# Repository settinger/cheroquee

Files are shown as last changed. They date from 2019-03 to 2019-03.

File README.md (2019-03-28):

# Cheroquee

A proof-of-concept scrolling LED marquee with support for Cherokee input. Could easily be extended to support variable-width glyphs, fancier scrolling, pre-programmed text cycles, etc. Potentially useful as a starting point for other orthographies that don't have pixel fonts: Inuktitut, N'Ko, maybe vertical Mongolian?

Requires [py-spidev](https://pypi.org/project/spidev/). `pip install py-spidev`

Usage: `python3 cheroquee.py MESSAGE`, e.g. `python3 cheroquee.py "ᏣᎳᎩᎯ ᎠᏰᎵ"`

For more info: www.settinger.net/projects.php?project=cheroquee

* * * * *

## Cultural note

Let's be clear, I'm a white non-Cherokee-speaker showing off a potential tech tool for Cherokee-speakers. I worry about being insensitive, insulting, condescending, or inaccurate; I strive to be none of those things as I present this project. But if I screw up or speak out-of-turn, please tell me!

My scope and intentions are pretty small, here. There's a long history of prescriptivist anglophones unceremoniously thrusting new language tools on people, and I am not trying to be that! There are lots of immediately-apparent ways to improve it, however, **I'll only continue this project if someone else has a real, acceptable use for it**. If you write to me with one, I'll work with you at whatever level of involvement you deem appropriate. Thanks.

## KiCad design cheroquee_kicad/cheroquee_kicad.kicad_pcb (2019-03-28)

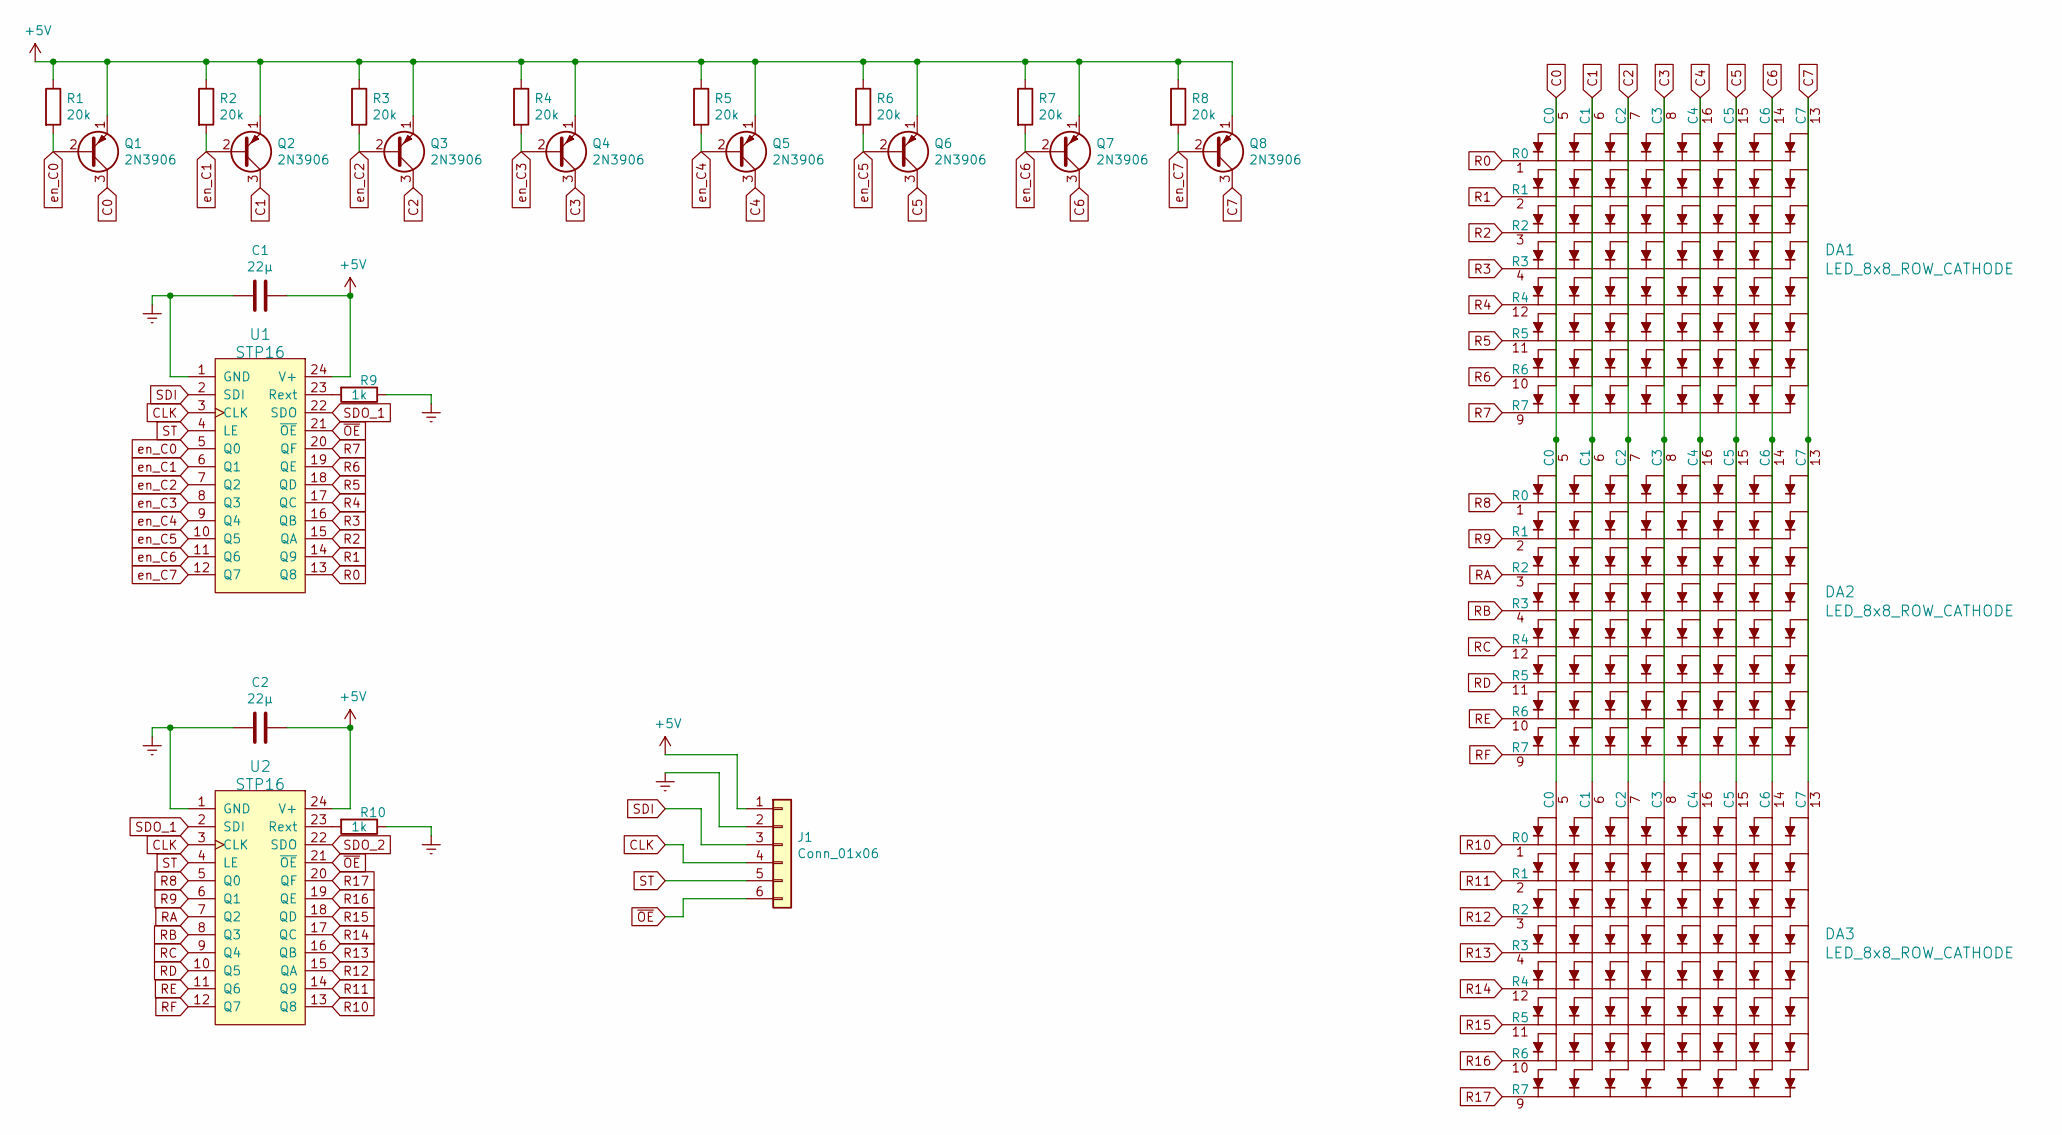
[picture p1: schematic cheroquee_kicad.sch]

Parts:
C1, C2: 22μ; Pin_Header_Straight_1x02_Pitch2.54mm
DA1, DA2, DA3: LED_8x8_ROW_CATHODE; 8x8_LED
J1: Conn_01x06; Socket_Strip_Straight_1x06_Pitch2.54mm
Q1, Q2, Q3, Q4, Q5, Q6, Q7, Q8: 2N3906; breadboard_transistor
R1, R2, R3, R4, R5, R6, R7, R8: 20k; Pin_Header_Straight_1x02_Pitch2.54mm
R9, R10: 1k; Pin_Header_Straight_1x02_Pitch2.54mm
U1, U2: STP16; stp16_breakout_alt

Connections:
+5V: C1.1, C2.1, J1.1, Q1.1 (E), Q2.1 (E), Q3.1 (E), Q4.1 (E), Q5.1 (E), Q6.1 (E), Q7.1 (E), Q8.1 (E), R1.1, R2.1, R3.1, R4.1, R5.1, R6.1, R7.1, R8.1, U1.24 (V+), U2.24 (V+)
C0: DA1.5 (C0), DA2.5 (C0), DA3.5 (C0), Q1.3 (C)
C1: DA1.6 (C1), DA2.6 (C1), DA3.6 (C1), Q2.3 (C)
C2: DA1.7 (C2), DA2.7 (C2), DA3.7 (C2), Q3.3 (C)
C3: DA1.8 (C3), DA2.8 (C3), DA3.8 (C3), Q4.3 (C)
C4: DA1.16 (C4), DA2.16 (C4), DA3.16 (C4), Q5.3 (C)
C5: DA1.15 (C5), DA2.15 (C5), DA3.15 (C5), Q6.3 (C)
C6: DA1.14 (C6), DA2.14 (C6), DA3.14 (C6), Q7.3 (C)
C7: DA1.13 (C7), DA2.13 (C7), DA3.13 (C7), Q8.3 (C)
CLK: J1.4, U1.3 (CLK), U2.3 (CLK)
GNDREF: C1.2, C2.2, J1.2, R9.1, R10.1, U1.1 (GND), U2.1 (GND)
unnamed: R9.2, U1.23 (Rext)
unnamed: R10.2, U2.23 (Rext)
R0: DA1.1 (R0), U1.13 (Q8)
R1: DA1.2 (R1), U1.14 (Q9)
R2: DA1.3 (R2), U1.15 (QA)
R3: DA1.4 (R3), U1.16 (QB)
R4: DA1.12 (R4), U1.17 (QC)
R5: DA1.11 (R5), U1.18 (QD)
R6: DA1.10 (R6), U1.19 (QE)
R7: DA1.9 (R7), U1.20 (QF)
R8: DA2.1 (R0), U2.5 (Q0)
R9: DA2.2 (R1), U2.6 (Q1)
R10: DA3.1 (R0), U2.13 (Q8)
R11: DA3.2 (R1), U2.14 (Q9)
R12: DA3.3 (R2), U2.15 (QA)
R13: DA3.4 (R3), U2.16 (QB)
R14: DA3.12 (R4), U2.17 (QC)
R15: DA3.11 (R5), U2.18 (QD)
R16: DA3.10 (R6), U2.19 (QE)
R17: DA3.9 (R7), U2.20 (QF)
RA: DA2.3 (R2), U2.7 (Q2)
RB: DA2.4 (R3), U2.8 (Q3)
RC: DA2.12 (R4), U2.9 (Q4)
RD: DA2.11 (R5), U2.10 (Q5)
RE: DA2.10 (R6), U2.11 (Q6)
RF: DA2.9 (R7), U2.12 (Q7)
SDI: J1.3, U1.2 (SDI)
SDO_1: U1.22 (SDO), U2.2 (SDI)
SDO_2: U2.22 (SDO)
ST: J1.5, U1.4 (LE), U2.4 (LE)
en_C0: Q1.2 (B), R1.2, U1.5 (Q0)
en_C1: Q2.2 (B), R2.2, U1.6 (Q1)
en_C2: Q3.2 (B), R3.2, U1.7 (Q2)
en_C3: Q4.2 (B), R4.2, U1.8 (Q3)
en_C4: Q5.2 (B), R5.2, U1.9 (Q4)
en_C5: Q6.2 (B), R6.2, U1.10 (Q5)
en_C6: Q7.2 (B), R7.2, U1.11 (Q6)
en_C7: Q8.2 (B), R8.2, U1.12 (Q7)
~OE: J1.6, U1.21 (~OE), U2.21 (~OE)

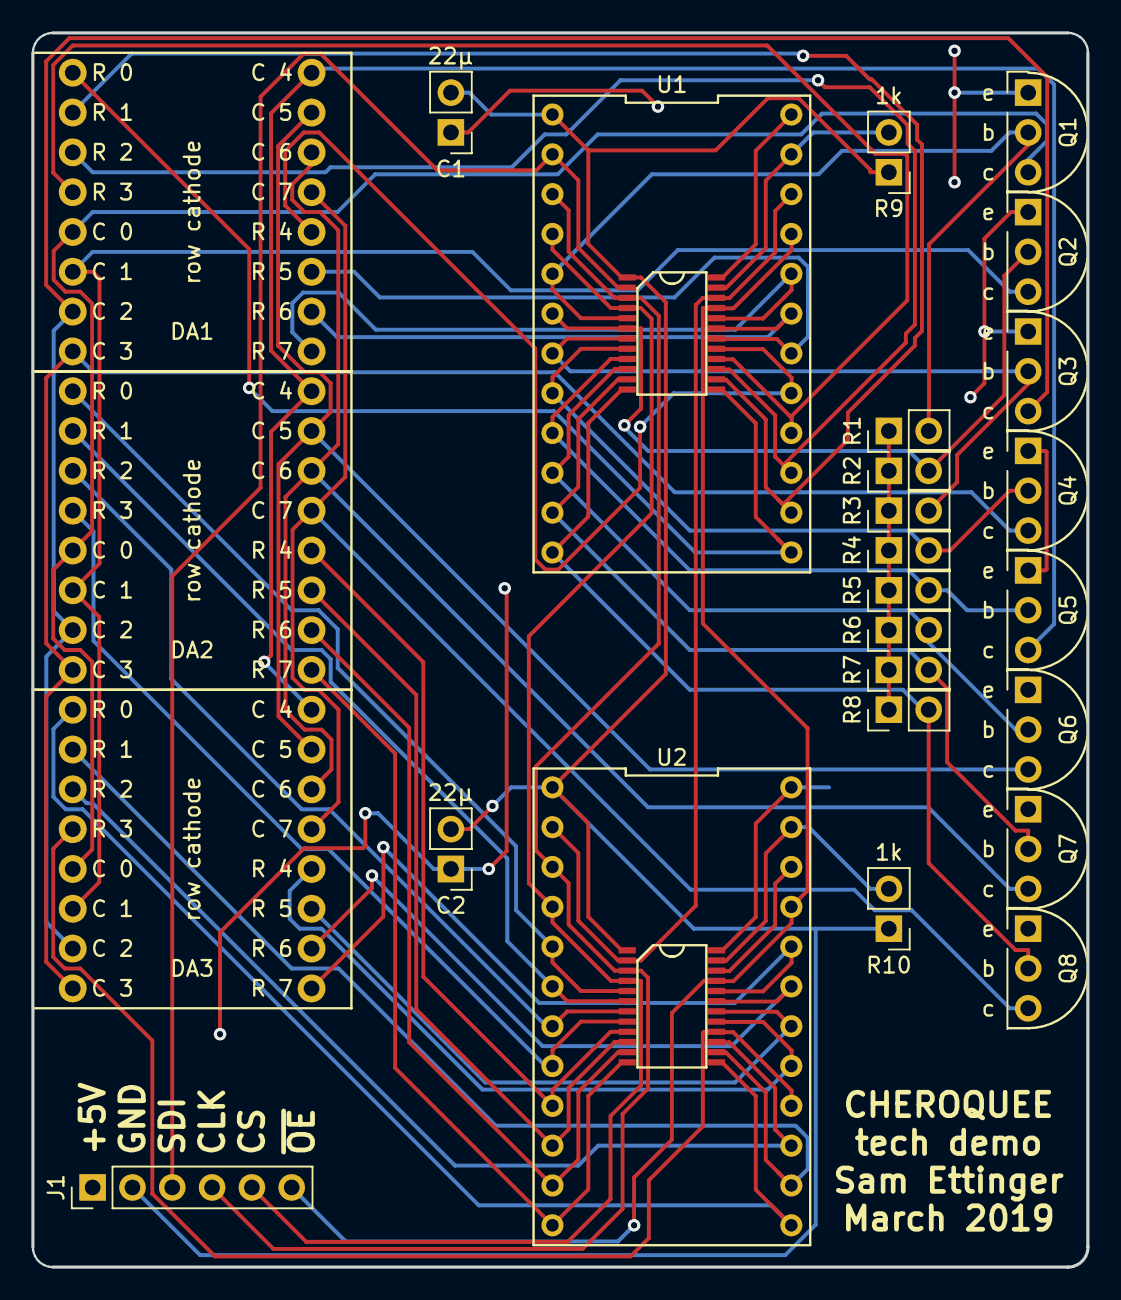
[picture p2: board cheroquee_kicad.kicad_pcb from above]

Board: 2 copper layers, 67.3 x 78.7 mm, 26 parts (0 on the bottom side), 49 nets.

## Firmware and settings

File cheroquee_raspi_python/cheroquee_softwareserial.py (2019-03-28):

# -*- coding: utf-8 -*-
"""
Use standard shift-register LED-driver communication protocol to drive an 8-pixel high scrolling marquee

@author: Sam
"""

from chardict import chardict
from bytemanip import byteToArray
import stp16
import sys
import numpy as np
import time

## definitions:
# Number of 8x8 panels
SIZE = 1

# Frames per second
FPS = 8

# Column refresh rate
f_refresh = 288

# (Ideally) frequency of PWM for LEDs
f_PWM = 500


## Check if a message was passed when the command line argument was called
arguments = len(sys.argv)-1

# If a message was passed, display it on the marquee; else, display default 
if arguments == 1:
    message = str(sys.argv[1])
else:
    message = u"ᏣᎳᎩᎯ ᎠᏰᎵ"

# Convert message to pixel array
# fullArray = np.zeros((8,8*(len(message)+3)))  # The "+3 is to add some padding between loops
fullArray = np.zeros((8,8*(len(message))))  # The "+3 is to add some padding between loops
for index, glyph in enumerate(message):
    columnstart = index*8
    glyphbytes = chardict[glyph]
    for row in range(8):
        fullArray[row, columnstart:columnstart+8] = byteToArray(glyphbytes[row])

# Initialize the marquee array
marqueeArray = np.zeros((8, 8*(SIZE+1)))
# Add the column-control signal to the end of the array
for x in range(8):
    marqueeArray[x,(8*SIZE)+x] = 1

# Initialize the marquee communications
stp16.init()

## Do a loop
columnPeriod = 1./f_refresh
framePeriod = 1./FPS

newColumn = 0
currTime = time.time()

while(1):
    # Transmit the marquee until it's time to update again
    frameStartTime = time.time()
    while (currTime-frameStartTime < framePeriod):
        # Transmit all eight rows
        for row in range(8):
            colStartTime = time.time()
            stp16.transmitBool(marqueeArray[row,:])
            while (currTime-colStartTime < columnPeriod):
                currTime = time.time()
        currTime = time.time()

    # update marquee
    marqueeArray[:, 0:-9] = marqueeArray[:, 1:-8]
    marqueeArray[:,-9] = fullArray[:,newColumn]
    newColumn += 1
    newColumn = newColumn % len(fullArray[0,:])

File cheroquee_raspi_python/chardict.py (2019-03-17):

# -*- coding: utf-8 -*-
# todo: make a version that isn't fixed-width


A   = [0x00, 0xf0, 0x88, 0x84, 0x84, 0x84, 0x88, 0xf0]
Ga  = [0x00, 0x38, 0x44, 0x20, 0x7c, 0x08, 0x44, 0x38]
Ka  = [0x00, 0x18, 0x04, 0x62, 0xa2, 0xa2, 0x44, 0x38]
Ha  = [0x00, 0x38, 0x10, 0x50, 0xbe, 0x52, 0x14, 0x18]
La  = [0x00, 0x82, 0x82, 0x92, 0x54, 0x54, 0x54, 0x28]
Ma  = [0x00, 0x1c, 0x08, 0x18, 0xe6, 0x50, 0x50, 0x20]
Na  = [0x00, 0x30, 0x48, 0x84, 0xfc, 0x84, 0x48, 0x30]
Hna = [0x00, 0x40, 0xe0, 0x40, 0x5c, 0x48, 0x38, 0x08]
Nah = [0x00, 0x38, 0x44, 0x80, 0x9c, 0x84, 0x44, 0x3c]
Qua = [0x00, 0xfe, 0x10, 0x10, 0x10, 0x10, 0x10, 0xfe]
S   = [0x00, 0x38, 0x44, 0x02, 0x1a, 0x52, 0xb2, 0x5c]
Sa  = [0x00, 0x84, 0x84, 0x84, 0xfc, 0x84, 0x48, 0x30]
Da  = [0x00, 0x40, 0x40, 0x40, 0x40, 0x44, 0x44, 0x38]
Ta  = [0x00, 0xaa, 0xaa, 0x92, 0x54, 0x54, 0x54, 0x28]
Dla = [0x00, 0x10, 0x28, 0x10, 0x6c, 0xaa, 0xaa, 0x44]
Tla = [0x00, 0x18, 0x24, 0x44, 0x40, 0x40, 0x40, 0x7c]
Tsa = [0x00, 0x38, 0x44, 0x8e, 0x80, 0x80, 0x44, 0x38]
Wa  = [0x00, 0x38, 0x44, 0x80, 0x80, 0x9c, 0x48, 0x36]
Ya  = [0x00, 0x1c, 0x22, 0x02, 0xba, 0x92, 0x92, 0x6c]

E   = [0x00, 0xf0, 0x88, 0x88, 0xf0, 0x90, 0x94, 0x8c]
Ge  = [0x00, 0x70, 0x20, 0x24, 0x34, 0x28, 0x20, 0x70]
He  = [0x00, 0x78, 0x84, 0x04, 0x24, 0x38, 0x20, 0x70]
Le  = [0x00, 0x0c, 0x10, 0x10, 0x70, 0x88, 0x88, 0x70]
Me  = [0x00, 0x22, 0x52, 0x8a, 0x8e, 0x8a, 0x52, 0x22]
Ne  = [0x00, 0x18, 0x24, 0x24, 0x24, 0x44, 0x44, 0xc4]
Que = [0x00, 0x1c, 0x22, 0x02, 0x82, 0x92, 0x92, 0x6c]
Se  = [0x00, 0x18, 0x28, 0x48, 0x88, 0xfc, 0x08, 0x08]
De  = [0x00, 0x70, 0x8c, 0x40, 0x3c, 0x10, 0x88, 0x70]
Te  = [0x00, 0xe0, 0x20, 0x28, 0x24, 0x24, 0x24, 0x18]
Tle = [0x00, 0x40, 0x40, 0x40, 0x40, 0x40, 0x40, 0x7c]
Tse = [0x00, 0xe4, 0x24, 0x28, 0x28, 0x30, 0x30, 0x20]
We  = [0x00, 0x26, 0x55, 0x55, 0x53, 0x51, 0x22, 0xdc] # Consider shifting everything one bit to the left
Ye  = [0x00, 0x38, 0x44, 0x58, 0x44, 0x44, 0xf8, 0x40]

I   = [0x00, 0xfe, 0x10, 0x10, 0x10, 0x10, 0x10, 0x10]
Gi  = [0x00, 0x44, 0x44, 0x24, 0x18, 0x08, 0x10, 0xe0]
Hi  = [0x00, 0x18, 0x24, 0x24, 0x3c, 0x44, 0x44, 0x88]
Li  = [0x00, 0x18, 0x24, 0x44, 0x40, 0x40, 0x40, 0x40]
Mi  = [0x00, 0x84, 0x84, 0x84, 0xfc, 0x84, 0x84, 0x84]
Ni  = [0x00, 0x40, 0x40, 0x40, 0x78, 0x44, 0x44, 0x44]
Qui = [0x00, 0xdc, 0x22, 0x52, 0x54, 0x50, 0x50, 0x20]
Si  = [0x00, 0x40, 0x40, 0x78, 0x44, 0x44, 0x44, 0x78]
Di  = [0x00, 0x04, 0x04, 0x04, 0x04, 0x0c, 0x94, 0x64]
Ti  = [0x00, 0x3c, 0x04, 0x04, 0x04, 0x0c, 0x94, 0x64]
Tli = [0x00, 0x3c, 0x44, 0x80, 0x80, 0x80, 0x44, 0x38]
Tsi = [0x00, 0x80, 0x80, 0xbc, 0xca, 0x88, 0x88, 0x88]
Wi  = [0x00, 0x38, 0x44, 0xe2, 0x92, 0x8e, 0x44, 0x38]
Yi  = [0x00, 0x1c, 0x08, 0x1c, 0x22, 0xa6, 0xaa, 0x44]

O   = [0x00, 0x1c, 0x08, 0x1c, 0x62, 0xa2, 0xaa, 0x44]
Go  = [0x00, 0x10, 0x28, 0x28, 0x44, 0x7c, 0x82, 0x82]
Ho  = [0x00, 0x70, 0x20, 0x20, 0x3c, 0x20, 0x20, 0x70]
Lo  = [0x00, 0x38, 0x44, 0x90, 0x98, 0x94, 0x44, 0x38]
Mo  = [0x00, 0x38, 0x10, 0x38, 0x04, 0x04, 0x44, 0x38]
No  = [0x00, 0xfc, 0x08, 0x10, 0x20, 0x40, 0x80, 0xfc]
Quo = [0x00, 0xcc, 0x4f, 0x25, 0x28, 0x28, 0x10, 0x10]
So  = [0x00, 0x38, 0x10, 0x58, 0x34, 0x10, 0x10, 0x38]
Do  = [0x00, 0x84, 0x84, 0x84, 0x48, 0x48, 0x30, 0x30]
Tlo = [0x00, 0x04, 0x44, 0xa4, 0x7e, 0x24, 0x24, 0x18]
Tso = [0x00, 0x44, 0x48, 0x50, 0x60, 0x50, 0x48, 0x44]
Wo  = [0x00, 0x48, 0xa4, 0xa4, 0xa4, 0xc4, 0x88, 0x70]
Yo  = [0x00, 0x38, 0x44, 0x80, 0xb8, 0xc4, 0x84, 0x84]

U   = [0x00, 0x24, 0x52, 0x8a, 0x8c, 0x88, 0x50, 0x20]
Gu  = [0x00, 0x04, 0x04, 0x04, 0x04, 0x44, 0x44, 0x38]
Hu  = [0x00, 0x3c, 0x20, 0x20, 0x20, 0x20, 0x20, 0x20]
Lu  = [0x00, 0x82, 0xc6, 0xc6, 0xaa, 0xaa, 0x92, 0x92]
Mu  = [0x00, 0x27, 0x22, 0x12, 0x0c, 0xe4, 0x48, 0x30]
Nu  = [0x00, 0x78, 0xc4, 0x04, 0xc4, 0x7c, 0x04, 0x04]
Quu = [0x00, 0x00, 0x04, 0x02, 0x8a, 0x92, 0x92, 0x6c]
Su  = [0x00, 0x60, 0xac, 0x70, 0x40, 0x4c, 0x44, 0x38]
Du  = [0x00, 0x38, 0x44, 0x20, 0x10, 0x08, 0x44, 0x38]
Tlu = [0x00, 0x36, 0x48, 0xd4, 0x14, 0x14, 0x14, 0x08]
Tsu = [0x00, 0x04, 0x04, 0x34, 0x4c, 0x84, 0x48, 0x30]
Wu  = [0x00, 0x08, 0x14, 0x14, 0x14, 0x14, 0x88, 0x70]
Yu  = [0x00, 0x3a, 0x45, 0x80, 0x80, 0x8e, 0x44, 0x38]

V   = [0x00, 0x00, 0x10, 0x00, 0x10, 0x10, 0x10, 0x38]
Gv  = [0x00, 0xfc, 0x80, 0x80, 0xf8, 0x80, 0x80, 0xfc]
Hv  = [0x00, 0x20, 0x50, 0x50, 0x50, 0x56, 0x24, 0xd8]
Lv  = [0x00, 0x78, 0x04, 0x44, 0x64, 0x5c, 0x04, 0x04]
Mv  = [0x00, 0x30, 0x40, 0x80, 0x80, 0x9c, 0x88, 0x78] # Unused
Nv  = [0x00, 0x20, 0x50, 0x88, 0x8d, 0x8a, 0x50, 0x20]
Quv = [0x00, 0x70, 0x88, 0x80, 0x48, 0x84, 0x84, 0x78]
Sv  = [0x00, 0x78, 0x44, 0x44, 0x58, 0x48, 0x44, 0x44]
Dv  = [0x00, 0x76, 0xaa, 0xa0, 0xa0, 0xa0, 0xa0, 0x40]
Tlv = [0x00, 0x78, 0x44, 0x44, 0x78, 0x40, 0x40, 0x40]
Tsv = [0x00, 0x35, 0x4a, 0x80, 0x80, 0x80, 0x4a, 0x35]
Wv  = [0x00, 0x18, 0x20, 0x40, 0x78, 0x44, 0x44, 0x38]
Yv  = [0x00, 0x78, 0x44, 0x44, 0x78, 0x44, 0x44, 0x78]

Blank = [0x00, 0x00, 0x00, 0x00, 0x00, 0x00, 0x00, 0x00]

chardict = {\
u'Ꭰ': A,
u'Ꭱ': E,
u'Ꭲ': I,
u'Ꭳ': O,
u'Ꭴ': U,
u'Ꭵ': V,
u'Ꭶ': Ga,
u'Ꭷ': Ka,
u'Ꭸ': Ge,
u'Ꭹ': Gi,
u'Ꭺ': Go,
u'Ꭻ': Gu,
u'Ꭼ': Gv,
u'Ꭽ': Ha,
u'Ꭾ': He,
u'Ꭿ': Hi,
u'Ꮀ': Ho,
u'Ꮁ': Hu,
u'Ꮂ': Hv,
u'Ꮃ': La,
u'Ꮄ': Le,
u'Ꮅ': Li,
u'Ꮆ': Lo,
u'Ꮇ': Lu,
u'Ꮈ': Lv,
u'Ꮉ': Ma,
u'Ꮊ': Me,
u'Ꮋ': Mi,
u'Ꮌ': Mo,
u'Ꮍ': Mu,
u'Ᏽ': Mv,
u'Ꮎ': Na,
u'Ꮏ': Hna,
u'Ꮐ': Nah,
u'Ꮑ': Ne,
u'Ꮒ': Ni,
u'Ꮓ': No,
u'Ꮔ': Nu,
u'Ꮕ': Nv,
u'Ꮖ': Qua,
u'Ꮗ': Que,
u'Ꮘ': Qui,
u'Ꮙ': Quo,
u'Ꮚ': Quu,
u'Ꮛ': Quv,
u'Ꮜ': Sa,
u'Ꮝ': S,
u'Ꮞ': Se,
u'Ꮟ': Si,
u'Ꮠ': So,
u'Ꮡ': Su,
u'Ꮢ': Sv,
u'Ꮣ': Da,
u'Ꮤ': Ta,
u'Ꮥ': De,
u'Ꮦ': Te,
u'Ꮧ': Di,
u'Ꮨ': Ti,
u'Ꮩ': Do,
u'Ꮪ': Du,
u'Ꮫ': Dv,
u'Ꮬ': Dla,
u'Ꮭ': Tla,
u'Ꮮ': Tle,
u'Ꮯ': Tli,
u'Ꮰ': Tlo,
u'Ꮱ': Tlu,
u'Ꮲ': Tlv,
u'Ꮳ': Tsa,
u'Ꮴ': Tse,
u'Ꮵ': Tsi,
u'Ꮶ': Tso,
u'Ꮷ': Tsu,
u'Ꮸ': Tsv,
u'Ꮹ': Wa,
u'Ꮺ': We,
u'Ꮻ': Wi,
u'Ꮼ': Wo,
u'Ꮽ': Wu,
u'Ꮾ': Wv,
u'Ꮿ': Ya,
u'Ᏸ': Ye,
u'Ᏹ': Yi,
u'Ᏺ': Yo,
u'Ᏻ': Yu,
u'Ᏼ': Yv,
u' ': Blank}

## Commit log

2019-03-17 Rearranged array to match circuit that (should) be arriving soon
2019-03-20 testing SPI as found on github.com/doceme/py-spidev
2019-03-23 Update the protoboard
    [cheroquee_kicad-B.Cu.gbr, cheroquee_kicad-B.Mask.gbr, cheroquee_kicad-B.SilkS.gbr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]
